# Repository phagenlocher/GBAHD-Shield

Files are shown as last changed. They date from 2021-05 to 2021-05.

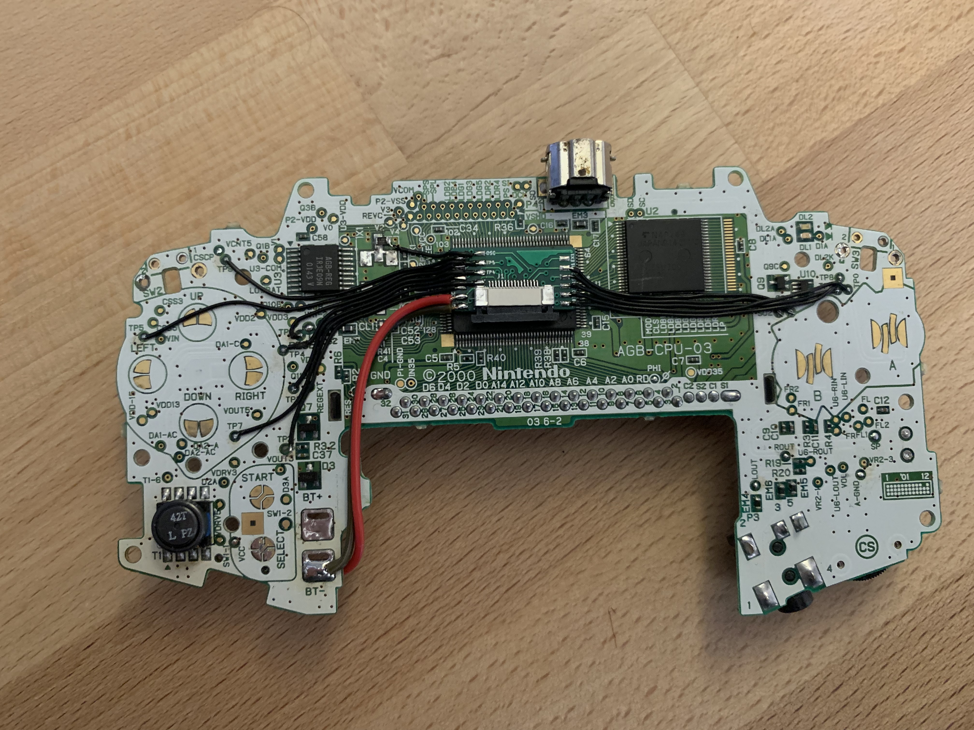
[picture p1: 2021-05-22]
static/wiki/agb-cpu-03_fixes.jpg

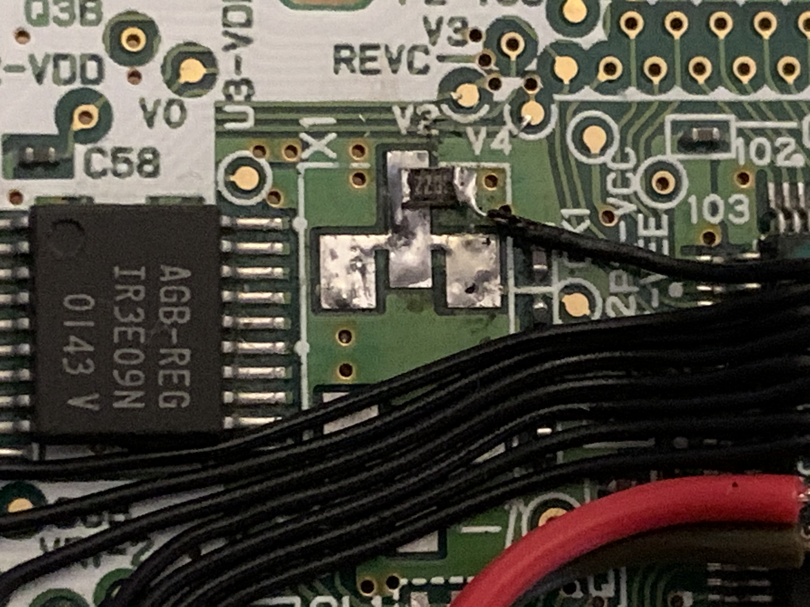
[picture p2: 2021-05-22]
static/wiki/agb_cpu_03_clock-res.jpg

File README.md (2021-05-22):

# gbaHD Shield
This is a shield for the [gbaHD project](https://github.com/zwenergy/gbaHD).  

This particular fork does change certain parts, but does not add any new features.

#### Features:
- Connects via female headers to the Edge board (shield)
- Has a FFC 40 pin connector for OGBA LCD connector. Need Type-B Cable (Reverse) vvv=======^^^
- Has a FFC 32 pin connector for OGBA LCD connector. Need Type-B Cable (Reverse) vvv=======^^^
- Has a FFC 34 pin connector for GBA-SP LCD connector. Need Type-A Cable (Direct) vvv=======vvv
- Has a FFC 16 pin connector for controls with a wire up board. Need Type-B Cable (Reverse) vvv=======^^^
- Has a ATMEGA328p for using a SNES connector to control the GBA.
- Has a high-side switch for GBA power controls (IGR).
- Has eight (8) testpoints on the bottom side for future features.

## Issues
- no known issues

## Contributing
If you wish to contribute, see something wrong or want to add a feature please make a pull request or leave an issue!

## BOM
|Reference	|Value							|
|---	|---						|
|C1, C3		|100nF 0805						|
|C2			|22uF 0805						|
|R1			|2.2K 0805						|
|R2			|1K 0805						|
|R3, R4		|10K 0805						|
|U1			|AMS1117-ADJ SOT223-3			|
|U2,U3		|74HC595 SOIC-16				|
|U4			|SNES 7Pin						|
|U5			|ATMEGA328p-AU					|
|SW1		|Push Button THT 6mm			|
|J2			|JUSHUO AFC07-S32FCC-00			|
|J3			|JUSHUO AFC07-S34FCC-00			|
|J4			|JUSHUO_AFC07-S16FCC-00			|
|J5			|JUSHUO AFC07-S40FCC-00			|
|J6			|PinHeader 1x6 2.54mm			|
|J7, J9		|PinHeader 1x8 2.54mm			|
|J8, J10	|PinHeader 1x10 2.54mm			|
|J11		|PinHeader 2x03 2.54mm			|
|Q1			|SI2301DS P-Chan MOSFET	SOT23	|

## Programming the MCU
In order to program the MCU, you need an arduino to use as ISP.  
Use the following image to wire up an arduino to the board to program it.  
**I would also recomend programming while it's not seated in the FPGA board.**
PCB Wireup  
After wiring the board, follow this tutorial to flash the the sketch to the board.  
[ICSP Tutorial](https://www.arduino.cc/en/pmwiki.php?n=Tutorial/ArduinoISP)
As target board choose "Arduino Pro or Pro Mini -  ATmega328p - 8MHz"
Fuses must be Low: 0xE2 High: 0xD9 Ext: 0xFF

## Choosing the supply voltage
As the OGBA and the GBA-SP use different battery technologies, they also require different voltages.
The OGBA needs approx. 3V (2x 1.5V from AA cells - 3.3 will also fit) and the GBA-SP needs 3.3 - 4.2V (Lithium battery - 4.0V will also fit).
Therefore we have a solder-jumper (JP1) which we use to choose between 3.3V and 4.0V.
Plus we need to solder-bridge J1 and J12 due to the fact, that the power-managing chip on the SP mainboard blocks the power on if it detected a
low battery recently. This will replace the power switch which therefore needs to be in **off position always!** 
**v20210406 Owners** If you want to use this board with an SP simply connect the J1 to the VCC-line on the shield and on the mainboard connect EX1 with BAT+ and VCC with VCC.
Workaround

## Images
PCB
Breakout Breakout PCB
Breakout_SP Breakout PCB for GBA SP
Hookup_SP Hookup

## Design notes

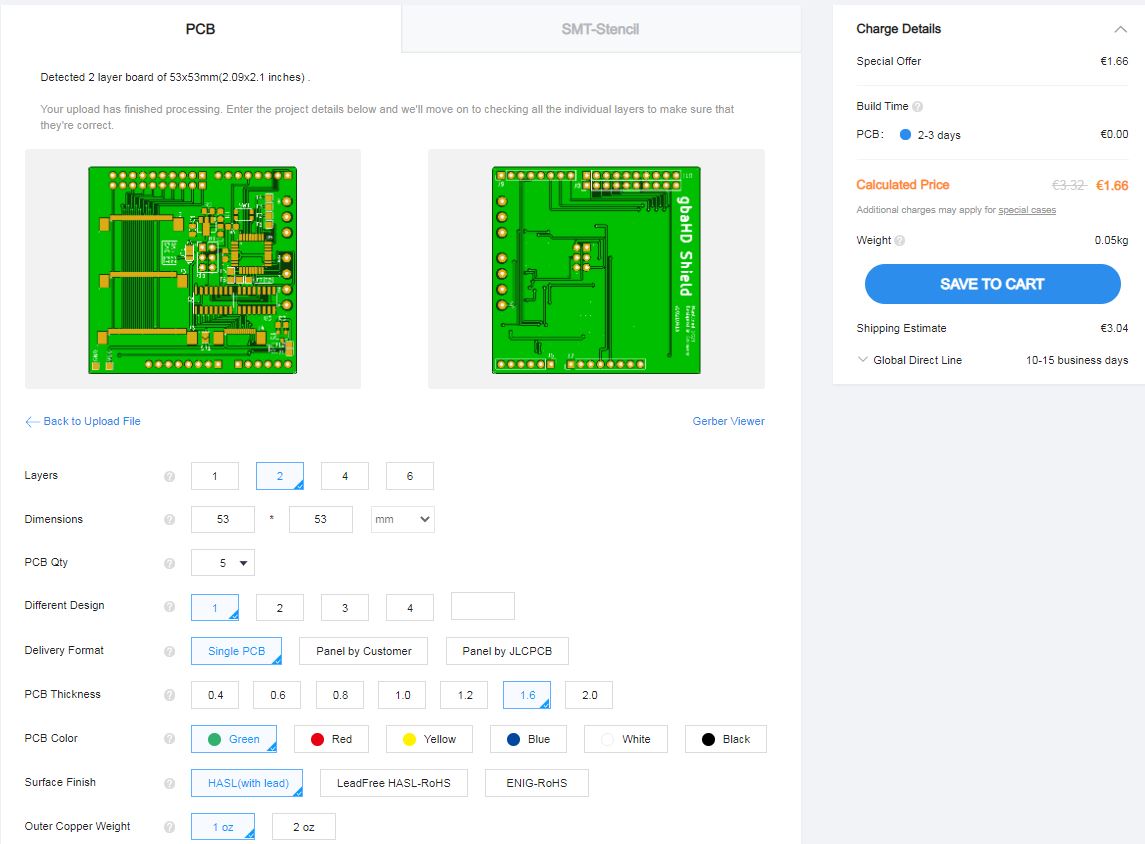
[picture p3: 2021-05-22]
static/wiki/jlcpcb1.JPG

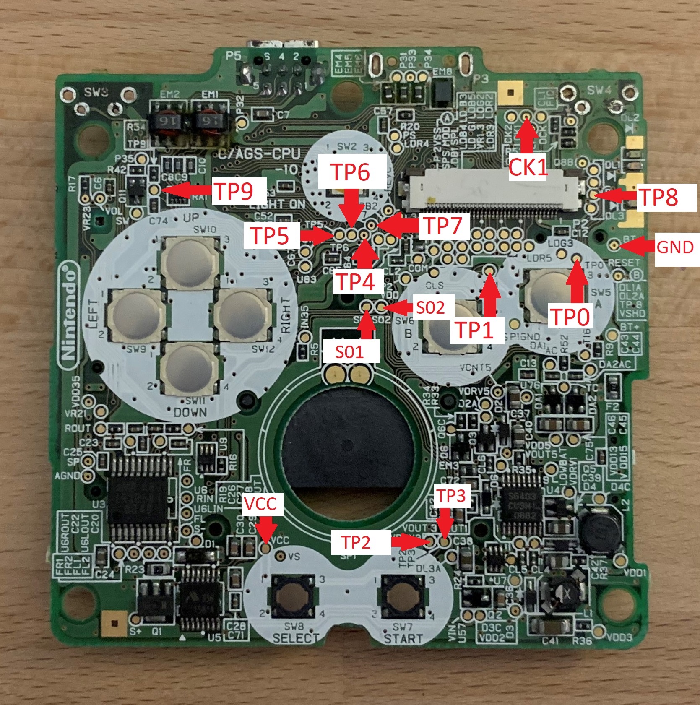
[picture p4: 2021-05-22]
static/wiki/sp_tp-points-marks.jpg

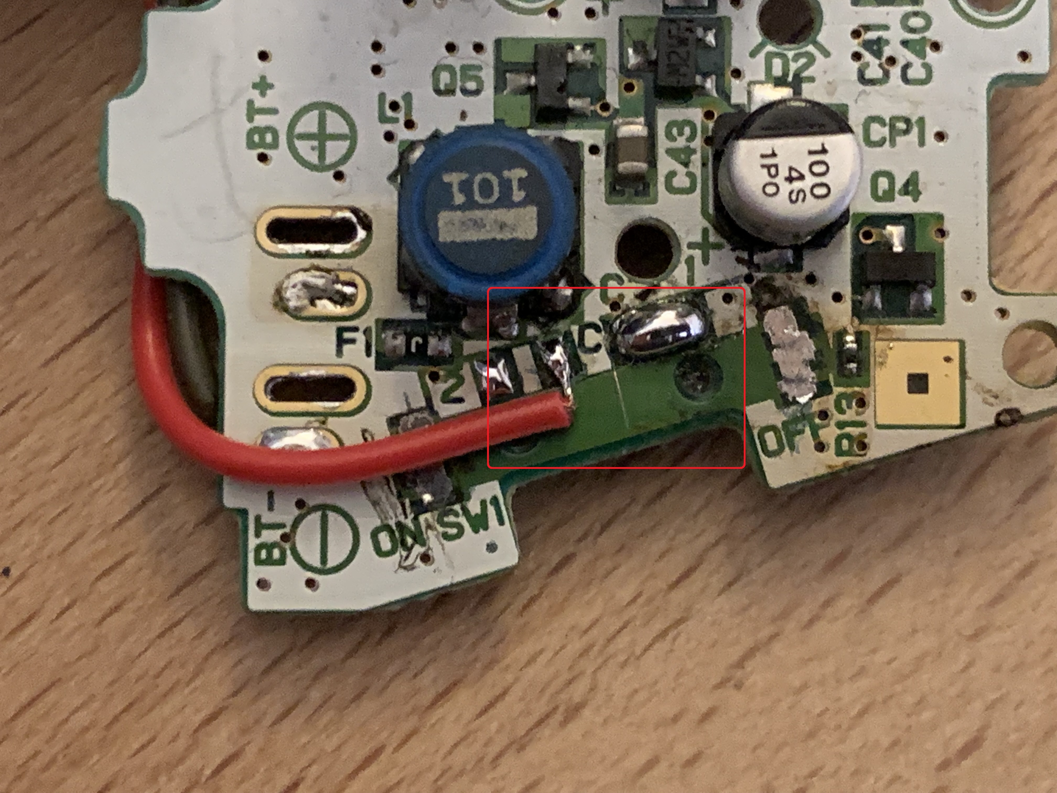
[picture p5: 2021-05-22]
static/wiki/agb-cpu-03_power.jpg

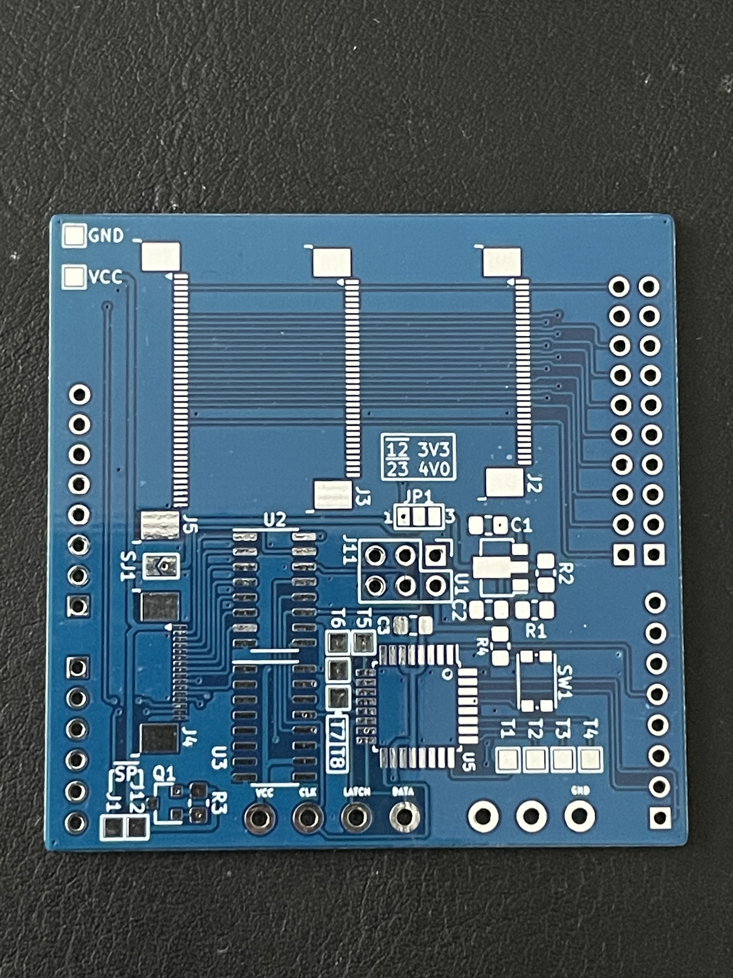
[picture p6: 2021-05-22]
static/wiki/20210416_front.jpeg

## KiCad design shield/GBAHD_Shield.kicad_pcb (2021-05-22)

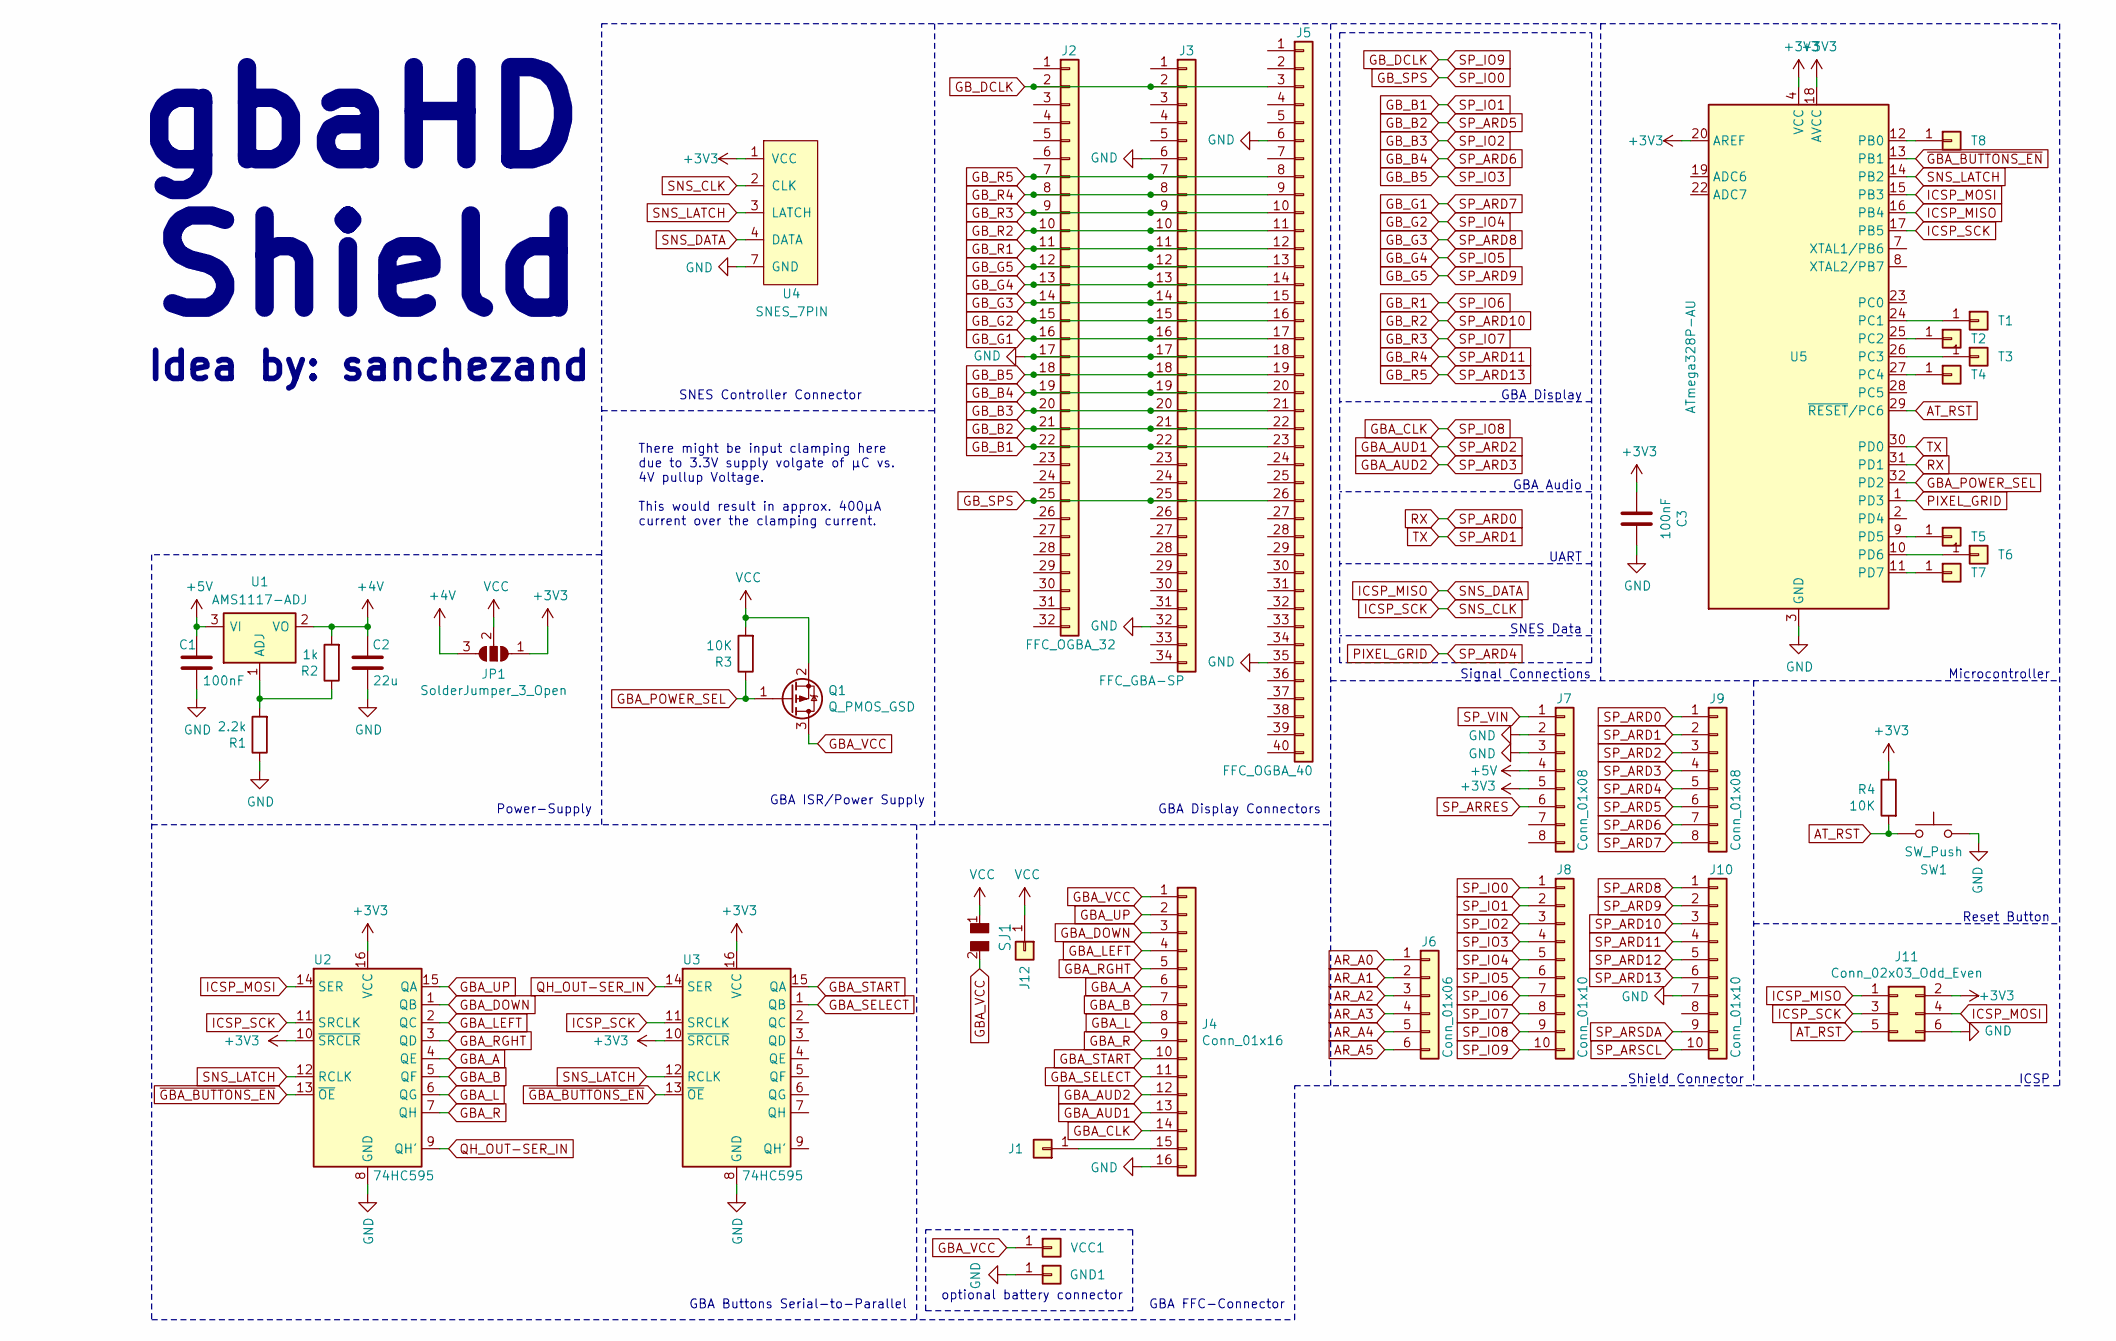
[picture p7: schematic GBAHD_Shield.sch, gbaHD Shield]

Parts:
C1, C3: 100nF; C_0805_2012Metric_Pad1.18x1.45mm_HandSolder
C2: 22u; C_0805_2012Metric_Pad1.18x1.45mm_HandSolder
GND1: Conn_01x01; TestPoint_Pad_1.5x1.5mm
J1, J12: Conn_01x01; TestPoint_Pad_1.5x1.5mm
J2: FFC_OGBA_32; TE_3-1734839-2_1x32-1MP_P0.5mm_Horizontal
J3: FFC_GBA-SP; TE_3-1734839-4_1x34-1MP_P0.5mm_Horizontal
J4: Conn_01x16; TE_1-1734839-6_1x16-1MP_P0.5mm_Horizontal
J5: FFC_OGBA_40; TE_4-1734839-0_1x40-1MP_P0.5mm_Horizontal
J6: Conn_01x06; PinHeader_1x06_P2.54mm_Vertical
J7, J9: Conn_01x08; PinHeader_1x08_P2.54mm_Vertical
J8, J10: Conn_01x10; PinHeader_1x10_P2.54mm_Vertical
J11: Conn_02x03_Odd_Even; PinHeader_2x03_P2.54mm_Vertical
JP1: SolderJumper_3_Open; SolderJumper-3_P1.3mm_Open_Pad1.0x1.5mm_NumberLabels
Q1: Q_PMOS_GSD; SOT-23
R1: 2.2k; R_0805_2012Metric_Pad1.20x1.40mm_HandSolder
R2: 1k; R_0805_2012Metric_Pad1.20x1.40mm_HandSolder
R3, R4: 10K; R_0805_2012Metric_Pad1.20x1.40mm_HandSolder
SJ1: SOLDER_JUMPER; SolderJumper-2_P1.3mm_Open_TrianglePad1.0x1.5mm
SW1: SW_Push; SW_PUSH_6mm
T1, T2, T3, T4, T5, T6, T7, T8: Conn_01x01; TestPoint_Pad_1.5x1.5mm
U1: AMS1117-ADJ; SOT-223-3_TabPin2
U2, U3: 74HC595; SOIC-16_3.9x9.9mm_P1.27mm
U4: SNES_7PIN
U5: ATmega328P-AU; TQFP-32_7x7mm_P0.8mm
VCC1: Conn_01x01; TestPoint_Pad_1.5x1.5mm

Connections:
+3V3: C3.2, J7.5, J11.2, JP1.1 (A), R4.1, U2.10 (~SRCLR), U2.16 (VCC), U3.10 (~SRCLR), U3.16 (VCC), U4.1 (VCC), U5.4 (VCC), U5.6 (VCC), U5.18 (AVCC), U5.20 (AREF)
+4V: C2.2, JP1.3 (B), R2.2, U1.2 (VO)
+5V: C1.2, J7.4, U1.3 (VI)
AR_A0: J6.1
AR_A1: J6.2
AR_A2: J6.3
AR_A3: J6.4
AR_A4: J6.5
AR_A5: J6.6
AT_RST: J11.5, R4.2, SW1.1, U5.29 (~RESET~/PC6)
GBA_A: J4.6, U2.4 (QE)
GBA_AUD1: J4.13, J9.3
GBA_AUD2: J4.12, J9.4
GBA_B: J4.7, U2.5 (QF)
GBA_CLK: J4.14, J8.9
GBA_DOWN: J4.3, U2.1 (QB)
GBA_L: J4.8, U2.6 (QG)
GBA_LEFT: J4.4, U2.2 (QC)
GBA_POWER_SEL: Q1.1 (G), R3.1, U5.32 (PD2)
GBA_R: J4.9, U2.7 (QH)
GBA_RGHT: J4.5, U2.3 (QD)
GBA_SELECT: J4.11, U3.1 (QB)
GBA_START: J4.10, U3.15 (QA)
GBA_UP: J4.2, U2.15 (QA)
GBA_VCC: J4.1, Q1.3 (D), SJ1.2, VCC1.1
GB_B1: J2.22, J3.22, J5.23, J8.2
GB_B2: J2.21, J3.21, J5.22, J9.6
GB_B3: J2.20, J3.20, J5.21, J8.3
GB_B4: J2.19, J3.19, J5.20, J9.7
GB_B5: J2.18, J3.18, J5.19, J8.4
GB_DCLK: J2.2, J3.2, J5.3, J8.10
GB_G1: J2.16, J3.16, J5.17, J9.8
GB_G2: J2.15, J3.15, J5.16, J8.5
GB_G3: J2.14, J3.14, J5.15, J10.1
GB_G4: J2.13, J3.13, J5.14, J8.6
GB_G5: J2.12, J3.12, J5.13, J10.2
GB_R1: J2.11, J3.11, J5.12, J8.7
GB_R2: J2.10, J3.10, J5.11, J10.3
GB_R3: J2.9, J3.9, J5.10, J8.8
GB_R4: J2.8, J3.8, J5.9, J10.4
GB_R5: J2.7, J3.7, J5.8, J10.6
GB_SPS: J2.25, J3.25, J5.26, J8.1
GND: C1.1, C2.1, C3.1, GND1.1, J2.17, J3.6, J3.17, J3.32, J4.16, J5.6, J5.18, J5.35, J7.2, J7.3, J10.7, J11.6, R1.1, SW1.2, U2.8 (GND), U3.8 (GND), U4.7 (GND), U5.3 (GND), U5.5 (GND), U5.21 (GND)
ICSP_MISO: J11.1, U4.4 (DATA), U5.16 (PB4)
ICSP_MOSI: J11.4, U2.14 (SER), U5.15 (PB3)
ICSP_SCK: J11.3, U2.11 (SRCLK), U3.11 (SRCLK), U4.2 (CLK), U5.17 (PB5)
unnamed: J1.1, J4.15
unnamed: R1.2, R2.1, U1.1 (ADJ)
unnamed: T1.1, U5.24 (PC1)
unnamed: T2.1, U5.25 (PC2)
unnamed: T3.1, U5.26 (PC3)
unnamed: T4.1, U5.27 (PC4)
unnamed: T5.1, U5.9 (PD5)
unnamed: T6.1, U5.10 (PD6)
unnamed: T7.1, U5.11 (PD7)
unnamed: T8.1, U5.12 (PB0)
PIXEL_GRID: J9.5, U5.1 (PD3)
QH_OUT-SER_IN: U2.9 (QH'), U3.14 (SER)
RX: J9.1, U5.31 (PD1)
SNS_LATCH: U2.12 (RCLK), U3.12 (RCLK), U4.3 (LATCH), U5.14 (PB2)
SP_ARD1: J9.2, U5.30 (PD0)
SP_ARD12: J10.5
SP_ARRES: J7.6
SP_ARSCL: J10.10
SP_ARSDA: J10.9
SP_VIN: J7.1
VCC: J12.1, JP1.2 (C), Q1.2 (S), R3.2, SJ1.1
~GBA_BUTTONS_EN~: U2.13 (~OE), U3.13 (~OE), U5.13 (PB1)

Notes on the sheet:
ICSP
Reset Button
Microcontroller
Shield Connector
Signal Connections
SNES Data
UART
GBA Display
GBA Audio
GBA Display Connectors
GBA FFC-Connector
GBA Buttons Serial-to-Parallel
SNES Controller Connector
GBA ISR/Power Supply
gbaHD Shield
Idea by: sanchezand
Power-Supply
optional battery connector
There might be input clamping here due to 3.3V supply volgate of µC vs. 4V pullup Voltage. This would result in approx. 400µA current over the clamping current.

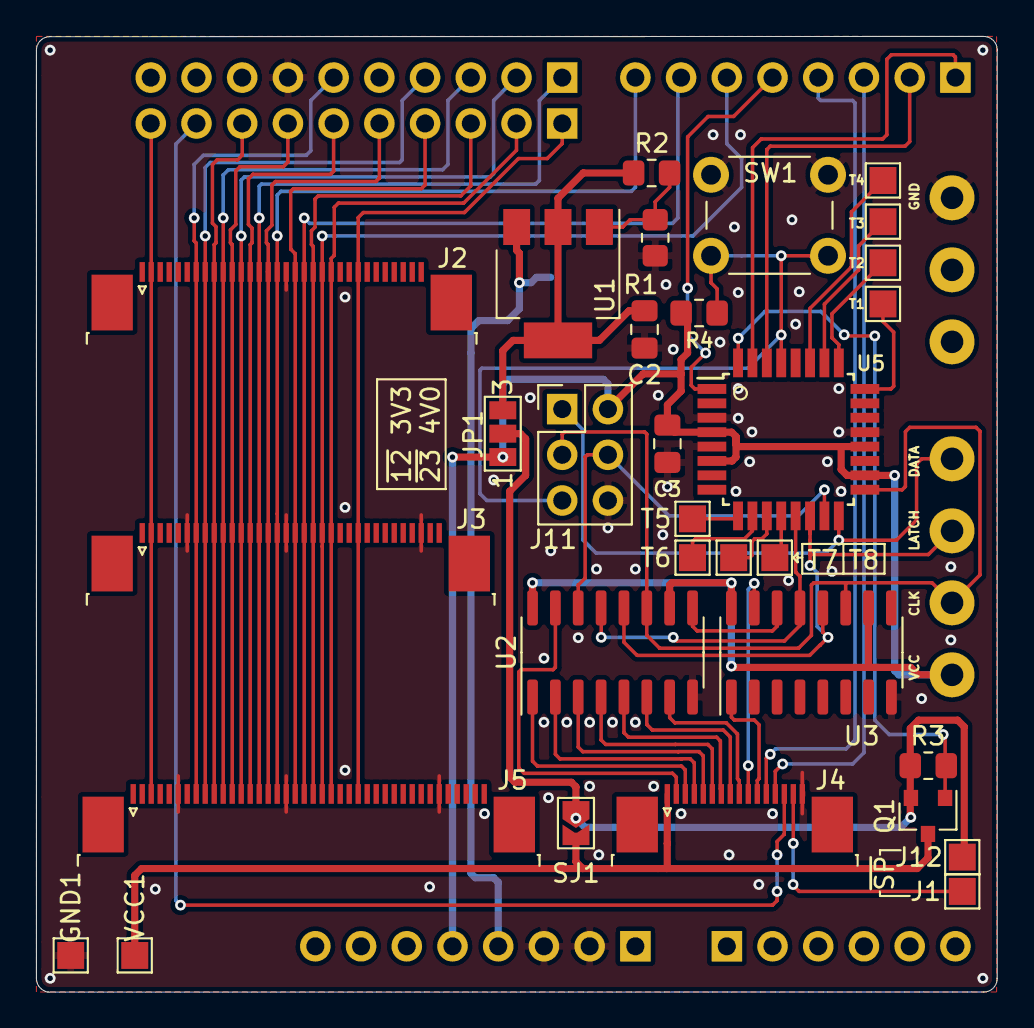
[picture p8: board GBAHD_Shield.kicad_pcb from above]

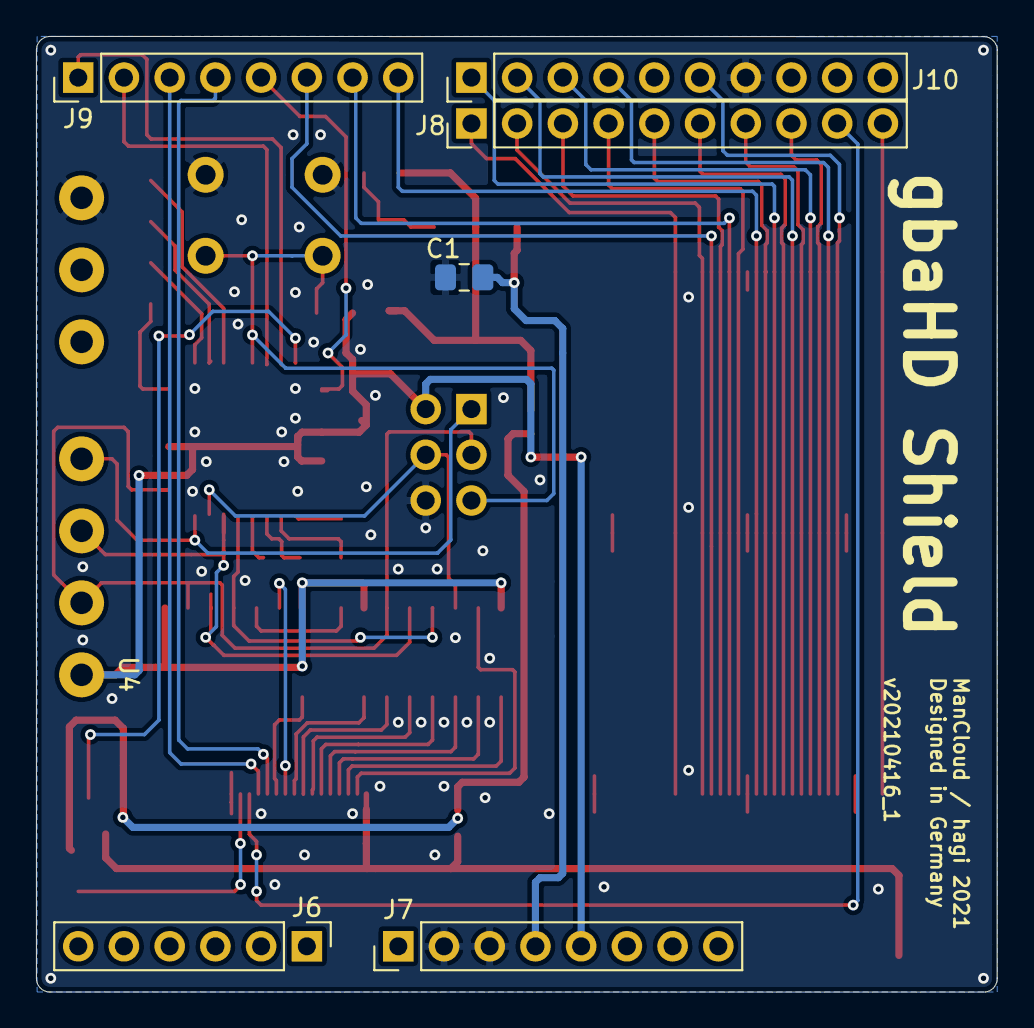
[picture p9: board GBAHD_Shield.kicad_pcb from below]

Board: 2 copper layers, 53.4 x 53.1 mm, 38 parts (7 on the bottom side), 57 nets.

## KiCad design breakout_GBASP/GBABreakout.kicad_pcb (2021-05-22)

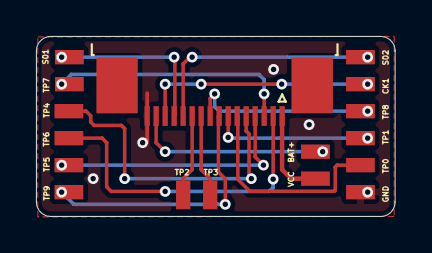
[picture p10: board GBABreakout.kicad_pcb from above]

Board: 2 copper layers, 19.9 x 10.0 mm, 17 parts (0 on the bottom side), 16 nets.

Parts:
J1: Conn_01x16; TE_1-1734839-6_1x16-1MP_P0.5mm_Horizontal
J2: VCC; SOLDER_PAD
J3: TP6; SOLDER_PAD
J4: TP7; SOLDER_PAD
J5: TP5; SOLDER_PAD
J6: TP4; SOLDER_PAD
J7: TP0; SOLDER_PAD
J8: TP1; SOLDER_PAD
J9: TP9; SOLDER_PAD
J10: TP8; SOLDER_PAD
J11: TP3; SOLDER_PAD
J12: TP2; SOLDER_PAD
J13: S02; SOLDER_PAD
J14: S01; SOLDER_PAD
J15: CK1; SOLDER_PAD
J16: BAT+; SOLDER_PAD
J17: GND; SOLDER_PAD

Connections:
BAT+: J1.15, J16.1
GBA_A: J1.6, J7.1
GBA_AUD1: J1.13, J14.1
GBA_AUD2: J1.12, J13.1
GBA_B: J1.7, J8.1
GBA_CLK: J1.14, J15.1
GBA_DOWN: J1.3, J4.1
GBA_L: J1.8, J9.1
GBA_LEFT: J1.4, J5.1
GBA_R: J1.9, J10.1
GBA_RIGHT: J1.5, J6.1
GBA_SELECT: J1.11, J12.1
GBA_START: J1.10, J11.1
GBA_UP: J1.2, J3.1
GBA_VCC: J1.1, J2.1
GND: J1.16, J17.1

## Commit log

2021-05-22 Switched Voltage Regulator to SOT-223 package and Push Button to THT
    [GBAHD_Shield.kicad_pcb, GBAHD_Shield.sch]
2021-05-22 Cleanup for shield pcb
    [GBAHD_Shield.kicad_pcb]
2021-05-22 More readable silkscreen on breakout boards
    [GBABreakout.kicad_pcb]
